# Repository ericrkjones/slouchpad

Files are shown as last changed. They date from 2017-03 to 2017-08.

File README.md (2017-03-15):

# slouchpad
A simple joypad for easy assembly in different types of enclosures.  

The joypad is broken into four main components:  
* Left pad, containing one joystick, d-pad, the select button, the menu buttor
* Right pad, containing one joystick, six primary buttons, and the start button
* Two shoulder pads, each containing two buttons.  

Signal List:
* 5 analog signals
* 13 digital signals
* VCC
* GND

## Hardware
Hardware designs are located in the "slouchpad_pcb" directory.
### Components
* Buttons
  * The buttons on all the pads are the Soft Tactile Buttons distributed by Adafruit Industries:
    * [Soft Tactile Button (8mm)](https://www.adafruit.com/products/3101)
  * These buttons provide the feel of a conductive silicone pad button without the expense and difficulty of producing the silicone parts.
* Joysticks
  * Joysticks are Mini 2-Axis Analog Thumbsticks distributed by Adafruit Industries:
    * [Mini 2-Axis Analog Thumbstick](https://www.adafruit.com/products/2765)
  * These joysticks have a feel that is very similar to a PSP joystick, but are available in a through-hole package.  

## License Information
The slouchpad hardware is released under [Creative Commons ShareAlike 4.0 International](https://creativecommons.org/licenses/by-sa/4.0/).  

The Mini Analog Thumbstick part layout was obtained from the [Adafruit-Mini-Analog-Thumbstick-Breakout-PCB](https://github.com/adafruit/Adafruit-Mini-Analog-Thumbstick-Breakout-PCB), designed by Ladyada for Adafruit Industries and released under the [Creative Commons Attribution-ShareAlike license](https://creativecommons.org/licenses/by-sa/3.0/).  Adafruit invests time and resources providing this open source design, please support Adafruit and open-source hardware by purchasing products from Adafruit!

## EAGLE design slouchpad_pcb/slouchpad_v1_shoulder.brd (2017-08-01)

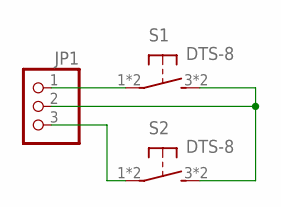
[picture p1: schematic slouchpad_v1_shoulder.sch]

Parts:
JP1: PINHD-1X3; 1X03
S1, S2: DTS-8

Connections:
GND: JP1.2, S1.3 (2), S1.4 (2), S2.3 (2), S2.4 (2)
S1: JP1.1, S1.1, S1.2 (1)
S2: JP1.3, S2.1, S2.2 (1)

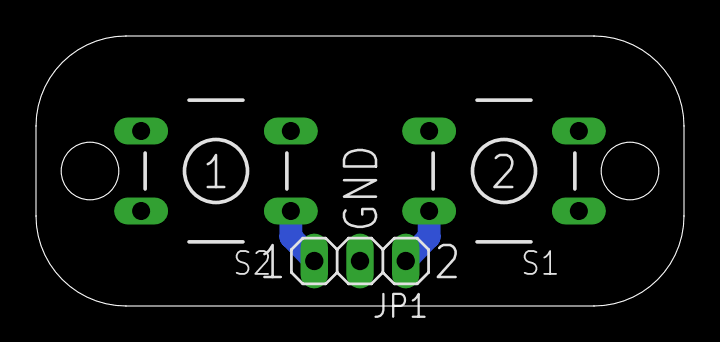
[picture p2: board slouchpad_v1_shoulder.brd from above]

Board: 2 copper layers, 36.0 x 15.0 mm, 3 parts (0 on the bottom side), 3 nets.

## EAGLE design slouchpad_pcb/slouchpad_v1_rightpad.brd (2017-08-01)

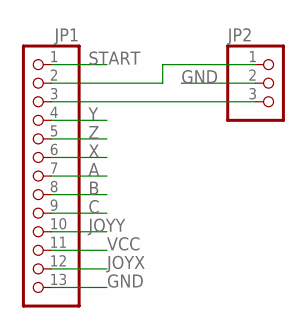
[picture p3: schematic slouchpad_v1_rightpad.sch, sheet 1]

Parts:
JP1: PINHD-1X13; 1X13
JP2: PINHD-1X3; 1X03

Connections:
A: JP1.7; also elsewhere on the board
B: JP1.8; also elsewhere on the board
C: JP1.9; also elsewhere on the board
GND: JP1.13, JP2.2; also elsewhere on the board
JOYX: JP1.12; also elsewhere on the board
JOYY: JP1.10; also elsewhere on the board
unnamed: JP1.2, JP2.1
unnamed: JP1.3, JP2.3
START: JP1.1; also elsewhere on the board
VCC: JP1.11; also elsewhere on the board
X: JP1.6; also elsewhere on the board
Y: JP1.4; also elsewhere on the board
Z: JP1.5; also elsewhere on the board

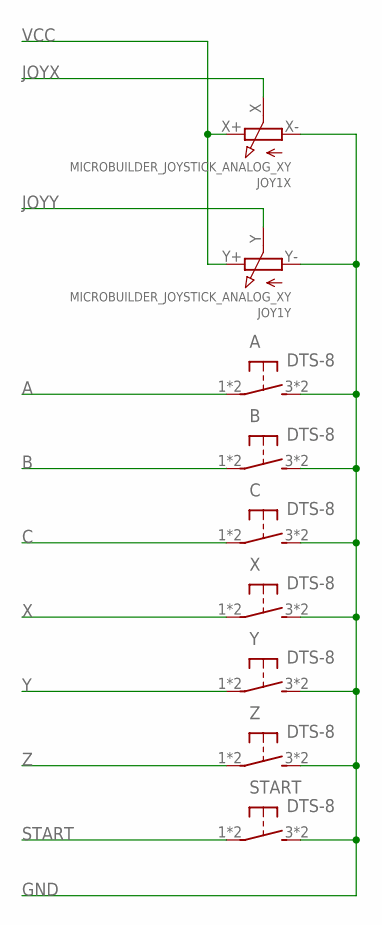
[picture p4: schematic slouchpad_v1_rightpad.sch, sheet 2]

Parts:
A: DTS-8
B: DTS-8
C: DTS-8
JOY1: MICROBUILDER_JOYSTICK_ANALOG_XY; MICROBUILDER_JOYSTICK_ANALOG_MINITHM
START: DTS-8
X: DTS-8
Y: DTS-8
Z: DTS-8

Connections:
A: A.1, A.2 (1); also elsewhere on the board
B: B.1, B.2 (1); also elsewhere on the board
C: C.1, C.2 (1); also elsewhere on the board
GND: A.3 (2), A.4 (2), B.3 (2), B.4 (2), C.3 (2), C.4 (2), JOY1.X- (A), JOY1.Y- (A), START.3 (2), START.4 (2), X.3 (2), X.4 (2), Y.3 (2), Y.4 (2), Z.3 (2), Z.4 (2); also elsewhere on the board
JOYX: JOY1.X (S); also elsewhere on the board
JOYY: JOY1.Y (S); also elsewhere on the board
START: START.1, START.2 (1); also elsewhere on the board
VCC: JOY1.X+ (E), JOY1.Y+ (E); also elsewhere on the board
X: X.1, X.2 (1); also elsewhere on the board
Y: Y.1, Y.2 (1); also elsewhere on the board
Z: Z.1, Z.2 (1); also elsewhere on the board

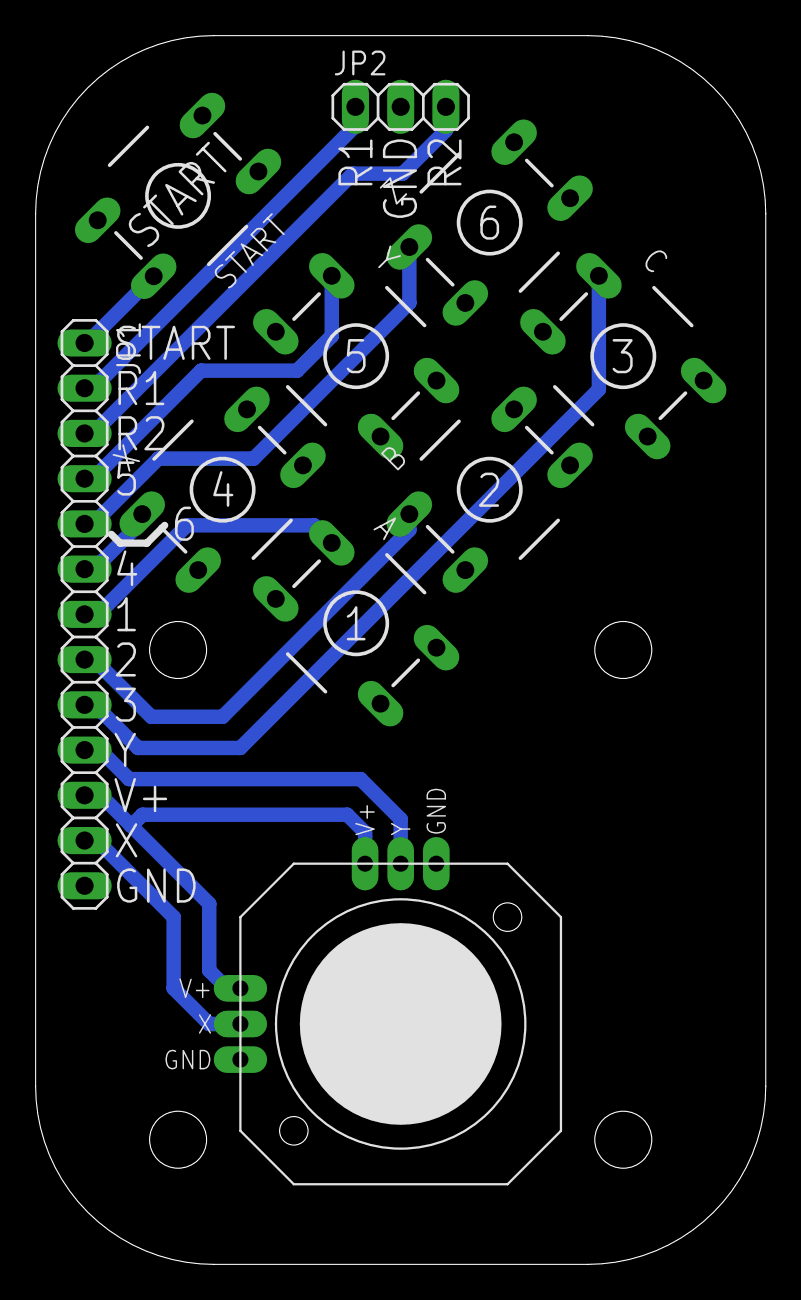
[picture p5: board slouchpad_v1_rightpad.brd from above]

Board: 2 copper layers, 41.0 x 69.0 mm, 10 parts (0 on the bottom side), 13 nets.

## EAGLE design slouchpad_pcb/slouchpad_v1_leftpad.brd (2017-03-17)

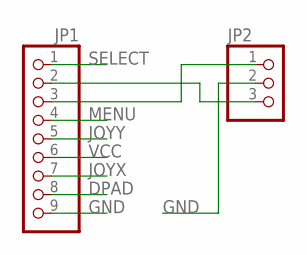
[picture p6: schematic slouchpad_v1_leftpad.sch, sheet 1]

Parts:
JP1: PINHD-1X9; 1X09
JP2: PINHD-1X3; 1X03

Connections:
DPAD: JP1.8; also elsewhere on the board
GND: JP1.9, JP2.2; also elsewhere on the board
JOYX: JP1.7; also elsewhere on the board
JOYY: JP1.5; also elsewhere on the board
MENU: JP1.4; also elsewhere on the board
unnamed: JP1.2, JP2.3
unnamed: JP1.3, JP2.1
SELECT: JP1.1; also elsewhere on the board
VCC: JP1.6; also elsewhere on the board

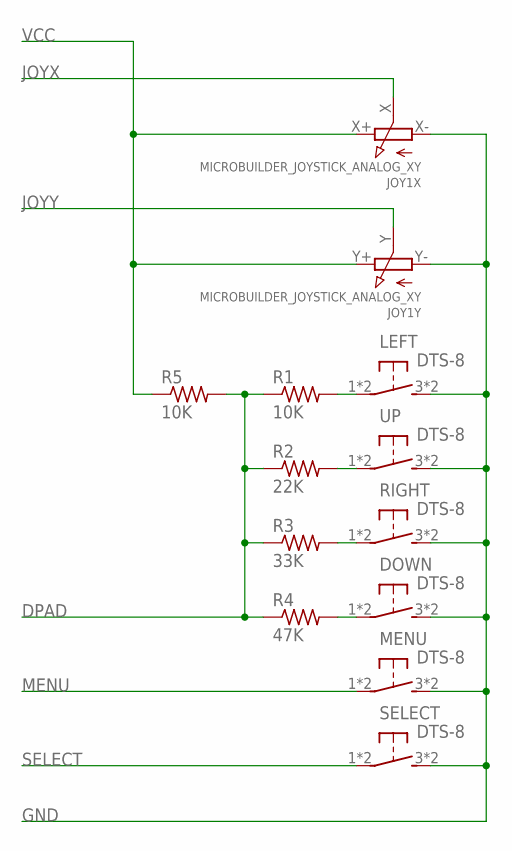
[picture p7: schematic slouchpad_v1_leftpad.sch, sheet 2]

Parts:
DOWN: DTS-8
JOY1: MICROBUILDER_JOYSTICK_ANALOG_XY; MICROBUILDER_JOYSTICK_ANALOG_MINITHM
LEFT: DTS-8
MENU: DTS-8
R1, R5: 10K; 0204/5
R2: 22K; 0204/5
R3: 33K; 0204/5
R4: 47K; 0204/5
RIGHT: DTS-8
SELECT: DTS-8
UP: DTS-8

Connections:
DPAD: R1.1, R2.1, R3.1, R4.1, R5.2; also elsewhere on the board
GND: DOWN.3 (2), DOWN.4 (2), JOY1.X- (A), JOY1.Y- (A), LEFT.3 (2), LEFT.4 (2), MENU.3 (2), MENU.4 (2), RIGHT.3 (2), RIGHT.4 (2), SELECT.3 (2), SELECT.4 (2), UP.3 (2), UP.4 (2); also elsewhere on the board
JOYX: JOY1.X (S); also elsewhere on the board
JOYY: JOY1.Y (S); also elsewhere on the board
MENU: MENU.1, MENU.2 (1); also elsewhere on the board
unnamed: LEFT.1, LEFT.2 (1), R1.2
unnamed: R3.2, RIGHT.1, RIGHT.2 (1)
unnamed: DOWN.1, DOWN.2 (1), R4.2
unnamed: R2.2, UP.1, UP.2 (1)
SELECT: SELECT.1, SELECT.2 (1); also elsewhere on the board
VCC: JOY1.X+ (E), JOY1.Y+ (E), R5.1; also elsewhere on the board

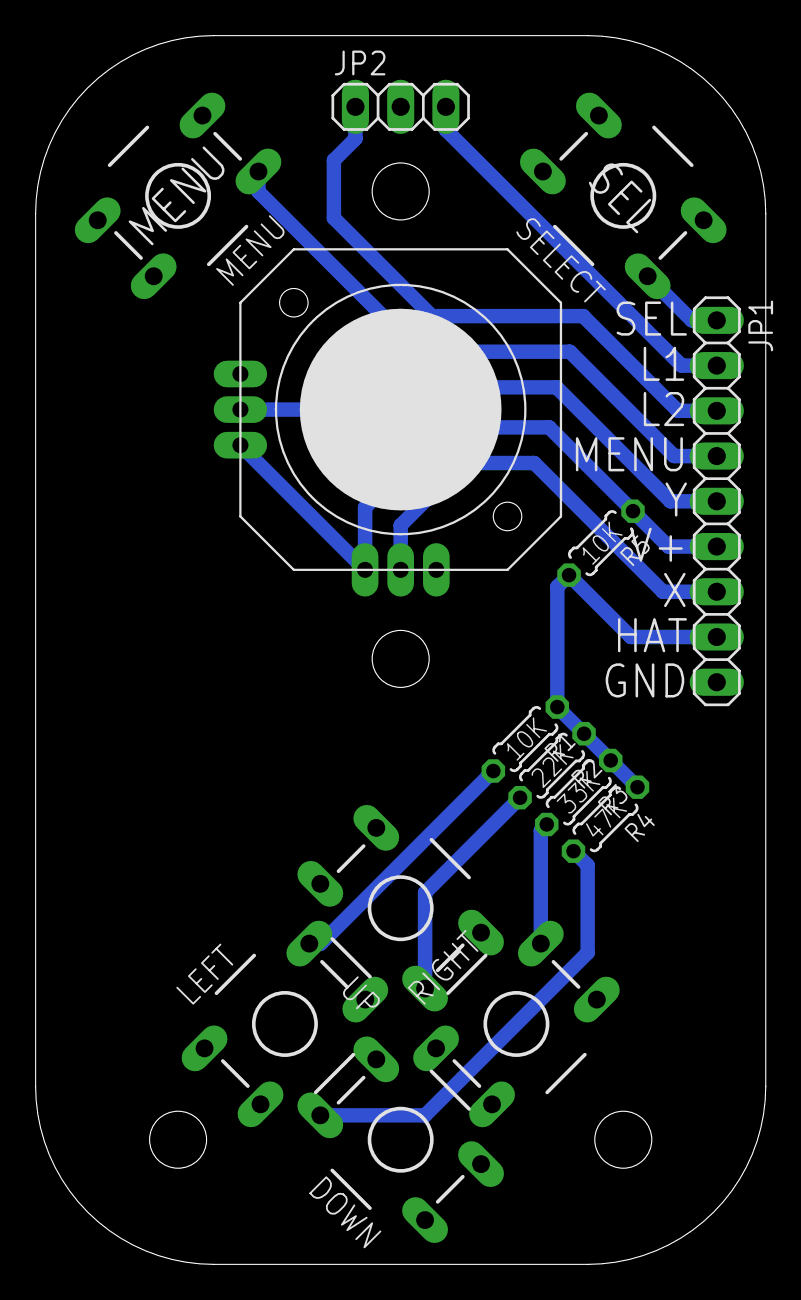
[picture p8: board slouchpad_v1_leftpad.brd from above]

Board: 2 copper layers, 41.0 x 69.0 mm, 14 parts (0 on the bottom side), 13 nets.

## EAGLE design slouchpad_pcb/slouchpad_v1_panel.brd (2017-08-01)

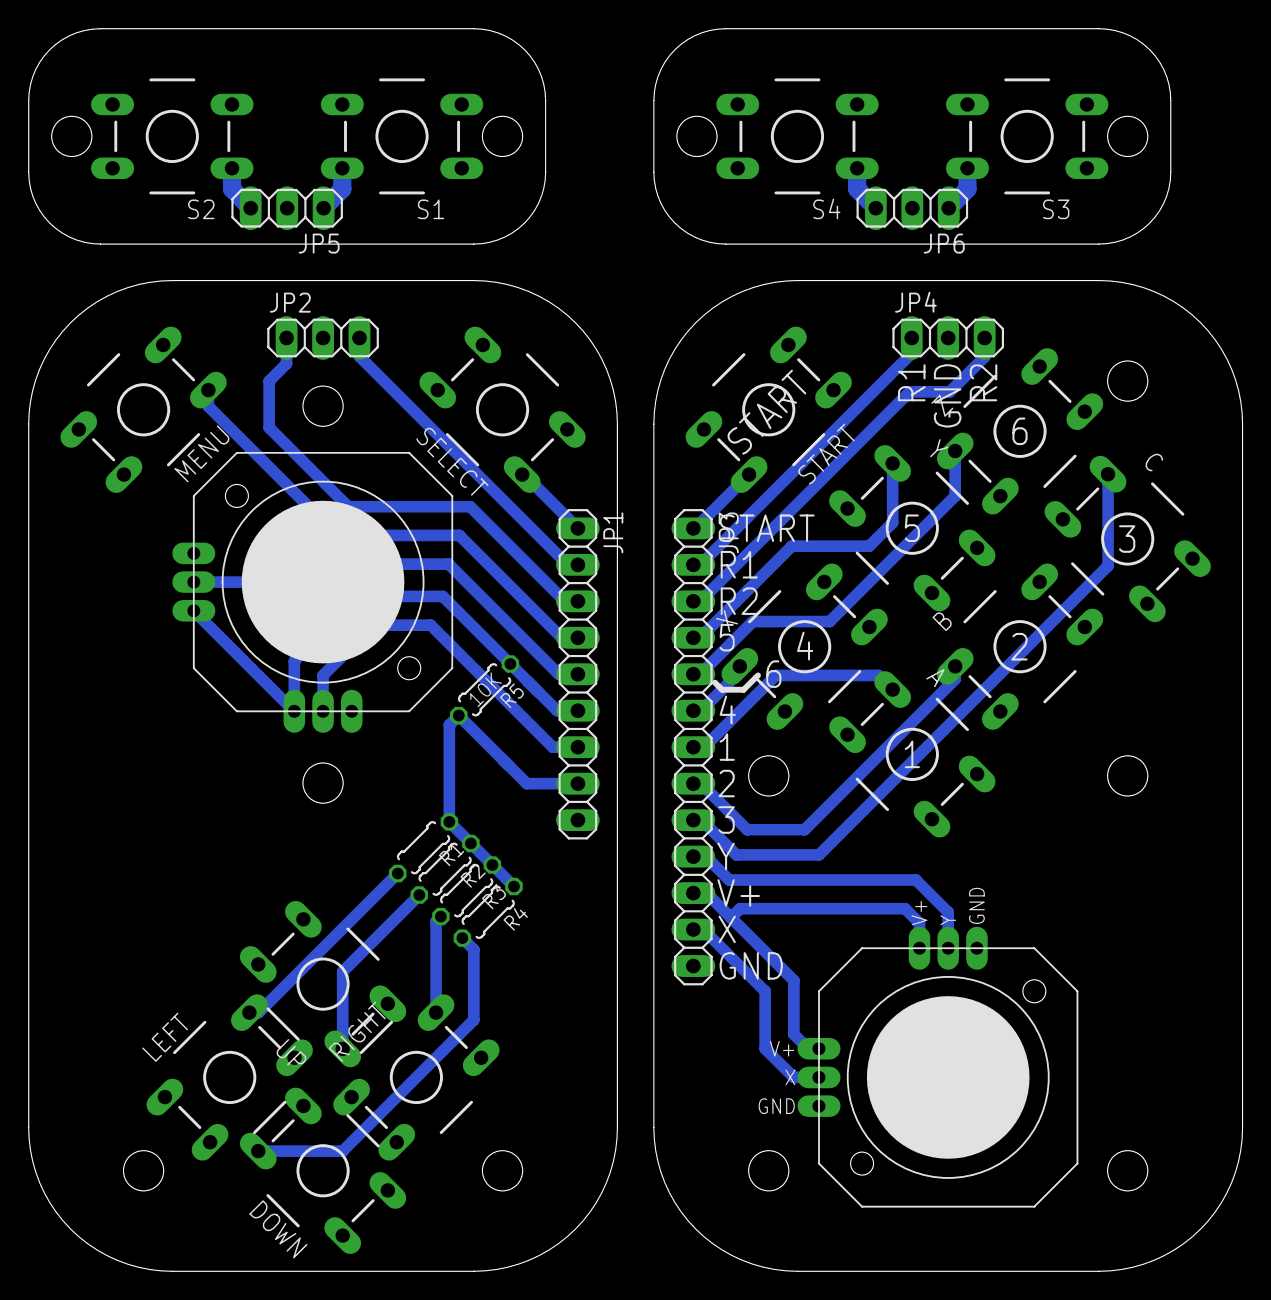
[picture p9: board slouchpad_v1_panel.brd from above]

Board: 2 copper layers, 84.5 x 86.5 mm, 30 parts (0 on the bottom side), 32 nets.

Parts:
A: DTS-8
B: DTS-8
C: DTS-8
DOWN: DTS-8
JOY1, JOY2: MICROBUILDER_JOYSTICK_ANALOG_XY; MICROBUILDER_JOYSTICK_ANALOG_MINITHM
JP1: 1X09
JP2, JP4, JP5, JP6: 1X03
JP3: 1X13
LEFT: DTS-8
MENU: DTS-8
R1, R5: 10K; 0204/5
R2: 22K; 0204/5
R3: 33K; 0204/5
R4: 47K; 0204/5
RIGHT: DTS-8
S1, S2, S3, S4: DTS-8
SELECT: DTS-8
START: DTS-8
UP: DTS-8
X: DTS-8
Y: DTS-8
Z: DTS-8

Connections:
A: A.1, A.2, JP3.7
B: B.1, B.2, JP3.8
C: C.1, C.2, JP3.9
DPAD: JP1.8, R1.1, R2.1, R3.1, R4.1, R5.2
GND: DOWN.3, DOWN.4, JOY1.X-, JOY1.Y-, JP1.9, JP2.2, LEFT.3, LEFT.4, MENU.3, MENU.4, RIGHT.3, RIGHT.4, SELECT.3, SELECT.4, UP.3, UP.4
GND1: A.3, A.4, B.3, B.4, C.3, C.4, JOY2.X-, JOY2.Y-, JP3.13, JP4.2, START.3, START.4, X.3, X.4, Y.3, Y.4, Z.3, Z.4
GND2: JP5.2, S1.3, S1.4, S2.3, S2.4
GND3: JP6.2, S3.3, S3.4, S4.3, S4.4
JOYX: JOY1.X, JP1.7
JOYX1: JOY2.X, JP3.12
JOYY: JOY1.Y, JP1.5
JOYY1: JOY2.Y, JP3.10
MENU: JP1.4, MENU.1, MENU.2
unnamed: JP1.2, JP2.3
unnamed: JP1.3, JP2.1
unnamed: LEFT.1, LEFT.2, R1.2
unnamed: R3.2, RIGHT.1, RIGHT.2
unnamed: DOWN.1, DOWN.2, R4.2
unnamed: R2.2, UP.1, UP.2
unnamed: JP3.2, JP4.1
unnamed: JP3.3, JP4.3
S1: JP5.1, S1.1, S1.2
S2: JP5.3, S2.1, S2.2
S3: JP6.1, S3.1, S3.2
S4: JP6.3, S4.1, S4.2
SELECT: JP1.1, SELECT.1, SELECT.2
START: JP3.1, START.1, START.2
VCC: JOY1.X+, JOY1.Y+, JP1.6, R5.1
VCC1: JOY2.X+, JOY2.Y+, JP3.11
X: JP3.6, X.1, X.2
Y: JP3.4, Y.1, Y.2
Z: JP3.5, Z.1, Z.2

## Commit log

2017-03-14 Added partial eagle files via upload
    Eagle project "slouchpad_pcb" contains schematics and boards for pads and triggers. The "rightpad" and "shoulder" boards are the only ones that are fully completed. The "leftpad" file is still in dev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
    [slouchpad_v1_leftpad.brd, slouchpad_v1_leftpad.sch, slouchpad_v1_rightpad.brd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]
2017-03-14 Delete LICENSE
    Removed MIT License to comply with terms of Creative Commons ShareAlike 4.0 International, inherited from SparkFun Arduino Pro Micro project.
2017-03-14 Update README.md
    Modified License Information to specify the use of the Creative Commons ShareAlike 4.0 International to comply with the terms of that license inherited from the SparkFun Arduino Pro Micro.
2017-03-15 Retooled the project to be a modular joypad
    Rather than being a shield for the SparkFun Pro Micro Arduino, the slouchpad will simply be a modular joypad for use with any microcontroller.
    Modified the license to reflect the removal of the SparkFun Pro Micro
    Removed backup design files
    Created button layout for left thumb pad
    Modified all board positions to units of mm where possible.
    [slouchpad_v1_leftpad.brd, slouchpad_v1_leftpad.sch, slouchpad_v1_rightpad.brd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]
2017-03-15 Finished board layouts
    Cleaned up schematics
    [slouchpad_v1_leftpad.brd, slouchpad_v1_leftpad.sch, slouchpad_v1_rightpad.brd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]
2017-03-17 Finished silkscreen of boards
    Moved traces to bottom layer to represent design intention
    [slouchpad_v1_leftpad.brd, slouchpad_v1_rightpad.brd, slouchpad_v1_shoulder.brd]
2017-08-01 Added dimensions to baord drawings and fixed button 5 position to have correct spacing.
    [slouchpad_v1_panel.brd, slouchpad_v1_rightpad.brd, slouchpad_v1_shoulder.brd]
